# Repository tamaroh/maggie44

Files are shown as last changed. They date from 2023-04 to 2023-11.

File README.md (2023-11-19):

# maggie44
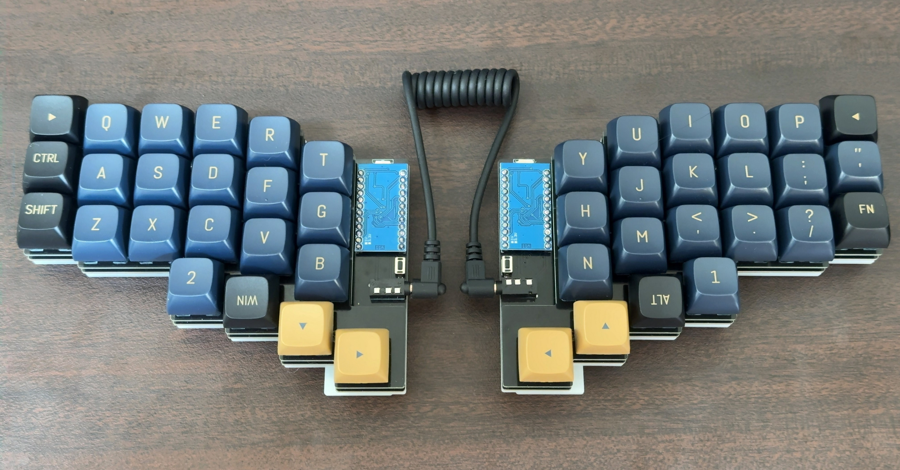
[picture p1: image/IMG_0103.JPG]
maggie44

maggie44はTamarohが初めて作成した試作カスタムキーボードです。
- 左右対象、分割、40%、カラムスタッガード
- T、Yキーがホームポジションに近く押しやすい
- 自然にハの字に手が配置される
- 尺屈角度や頻度を減らし手首にやさしいデザイン

## キーマップ
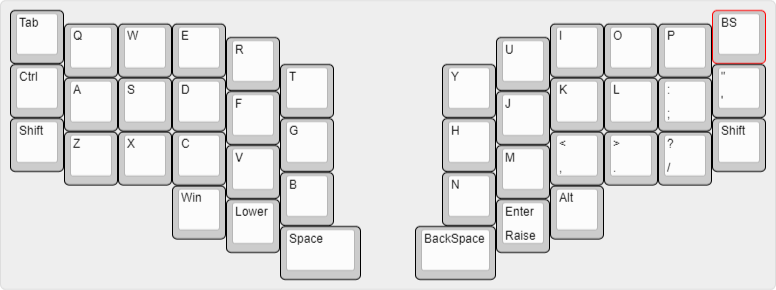
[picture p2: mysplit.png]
keymap

詳細については[ソースコード](https://github.com/tamaroh/qmk_firmware/tree/tamaroh/keyboards/maggie44/keymaps/default)を確認してください

## 必要なもの
|品名|数量|備考|入手先|
|----|----|----|----|
|PCB|2枚|左右別々のデータです<br>ver1.0は一部配線の修正が必要です|このRepositoryのデータから作成してください
|キープレート|2枚|裏返して左右どちらでも使えます|このRepositoryのデータから作成してください
|ボトムプレート大・小|各2枚|アクリル 2mm推奨|このRepositoryのデータから作成してください
|M2ネジ 4mm|20本|ボトムプレートの厚さによって長さは異なります|[遊舎工房](https://shop.yushakobo.jp/products/8006)など
|M2スペーサー 7mm|10個||[遊舎工房](https://shop.yushakobo.jp/products/a0800c2)など
|Pro Micro|2個|すべての互換品については動作を保障しません|[遊舎工房](https://shop.yushakobo.jp/products/pro-micro)など
|ピンヘッダー<br>またはコンスルー|12Pin x 4個||[遊舎工房](https://shop.yushakobo.jp/products/31)など
|タクトスイッチ<br>TS-1136-4.3|2個||[TALP KEYBOARD](https://talpkeyboard.net/items/5fa258a5f0b10814d183347f)など
|ダイオード<br>1N4148|44個|SMD/スルーホール両対応|[TALP KEYBOARD](https://talpkeyboard.net/items/6294480b0ebded1af895c437)など
|スイッチ用PCBソケット|44個|Cherry MX互換のみ対応|[TALP KEYBOARD](https://talpkeyboard.net/items/5e02c5405b120c792616bcf9)など
|TRRSジャック|2個|3.5mm 4極|[TALP KEYBOARD](https://talpkeyboard.net/items/5fa25a06da019c17f0664dc7)など
|TRRSケーブル|1本|TRSでも代用可|[TALP KEYBOARD](https://talpkeyboard.net/items/5e0c0d786c7d63073c5e8845)など
|USBケーブル|1本|Pro MicroとPCを接続できるもの|Amazonなど
|キースイッチ|44個|Cherry MX互換のみ対応|[遊舎工房](https://shop.yushakobo.jp/collections/all-switches)など
|キーキャップ|セット|すべて1Uです|[遊舎工房](https://shop.yushakobo.jp/collections/keycaps)など
|滑り止めゴム足|8個||ダイソーなど

## 必要な工具
- はんだごて
- コテ台、コテ先クリーナー
- はんだ
- 精密ドライバー
- ピンセット

## 制作手順
1. Pro Microにファームウェアを書き込みます。
  QMK Toolboxなどを使用してください。
1. ダイオードを半田付けします。
  SMDの場合縦線が入っている方の端子、スルーホールの場合黒い線がある方の端子を、基板上の縦線がある側に接続してください。
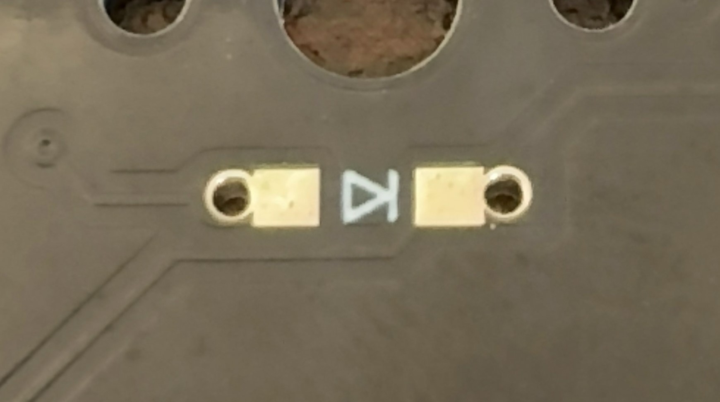
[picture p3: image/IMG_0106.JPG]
  
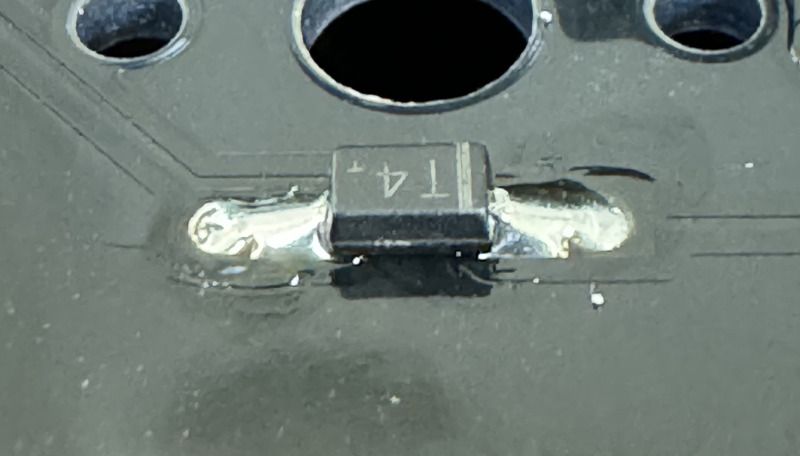
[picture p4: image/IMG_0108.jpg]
  
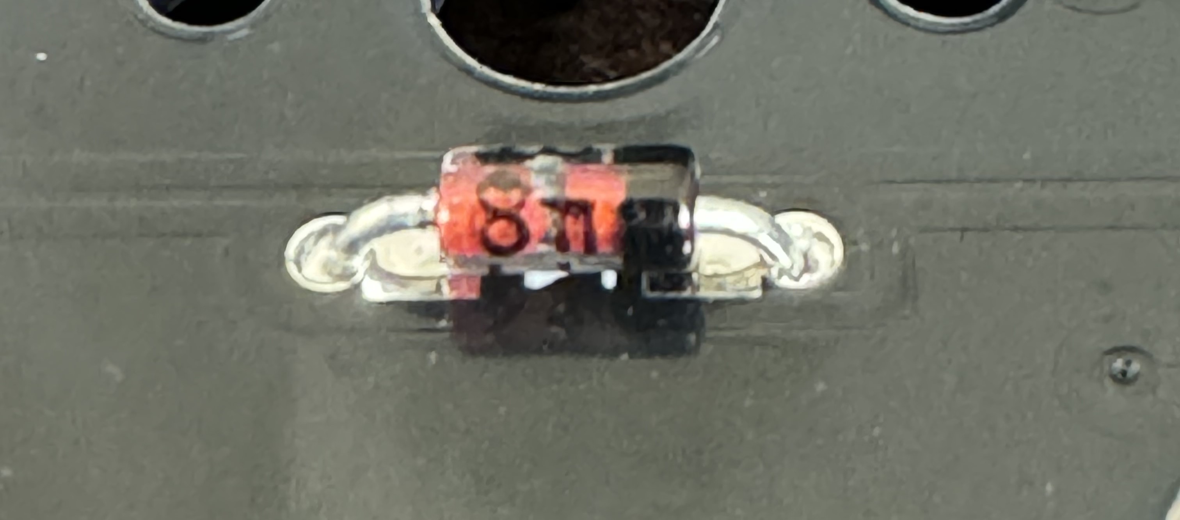
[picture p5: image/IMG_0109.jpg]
  
1. Pro Microを用意します。
  コンスルーを使用する場合は基板に仮置きして、適切にPro Microに半田付けしてください。
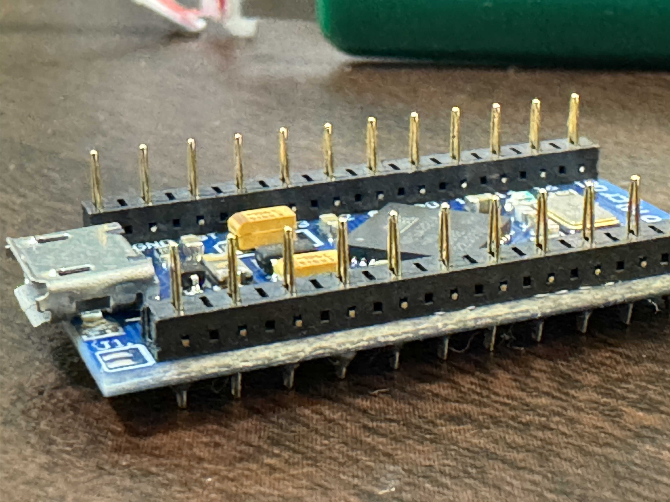
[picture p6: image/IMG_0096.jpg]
  
  ピンヘッダを使用する場合は修正が困難なため、向きや表裏を間違えないようにします。
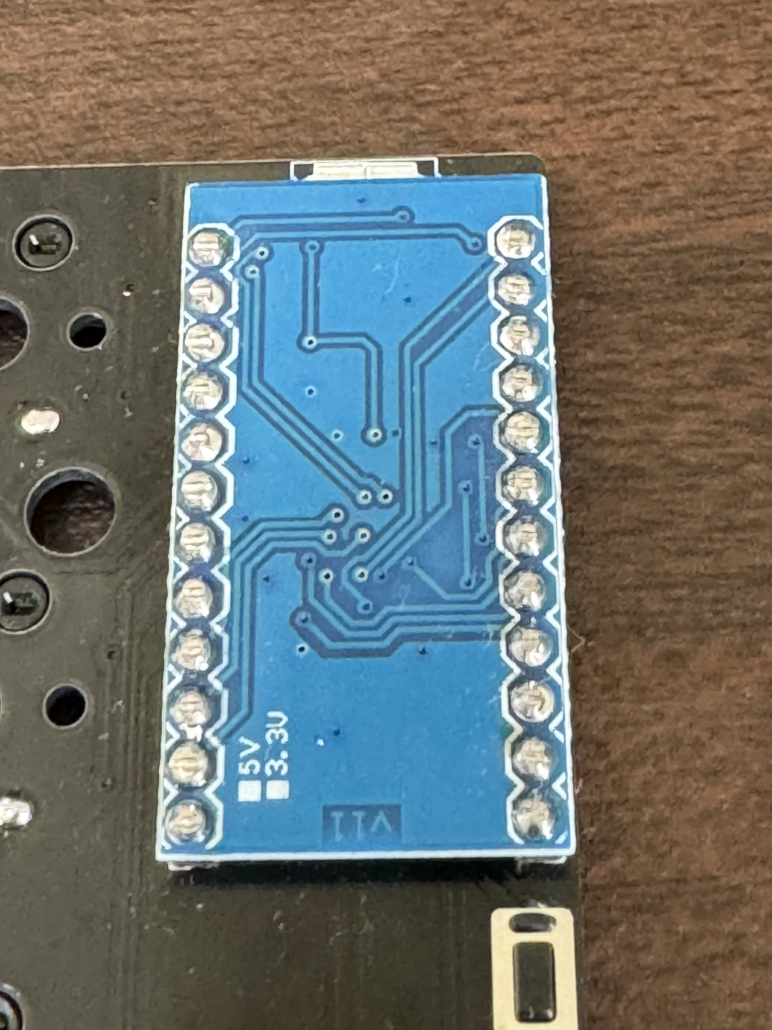
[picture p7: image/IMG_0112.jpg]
  
  ※USB-Cタイプなどコネクタ部が厚い場合は、ピンヘッダの高さが合わなかったり、コンスルーが抜けやすくなる可能性があります。
1. ソケットを半田付けします。シルク印刷に合わせて、スイッチの穴を塞がないようにします。
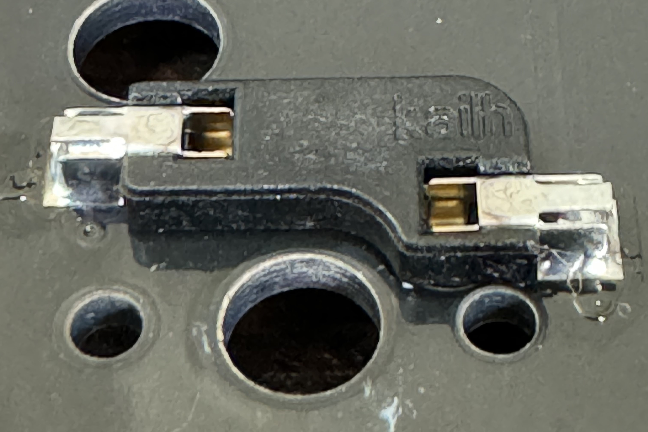
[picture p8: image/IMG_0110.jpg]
  
1. （Ver.1.0の基板のみ）右手用PCBのつながっていない箇所を、銅線などで半田付けしてつなぎます。
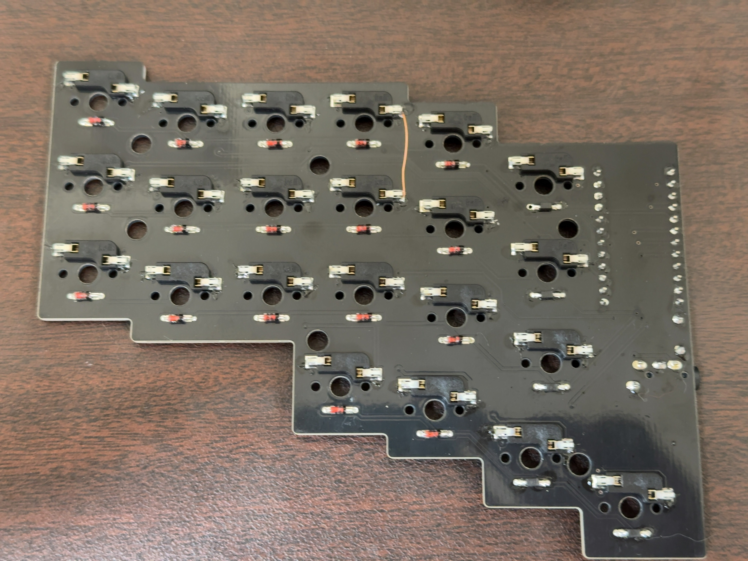
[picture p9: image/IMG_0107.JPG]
  
1. TRRSジャック、リセットスイッチを半田付けします。
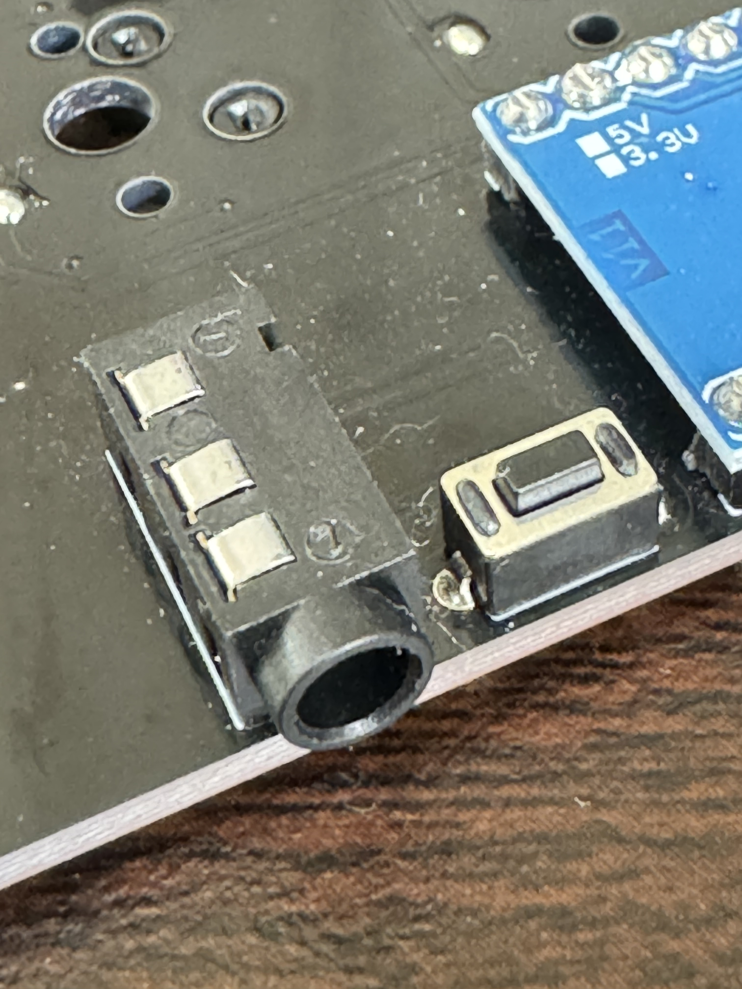
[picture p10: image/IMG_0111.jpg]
  
1. キースイッチを4個程度、先にキープレートに差し込みます。
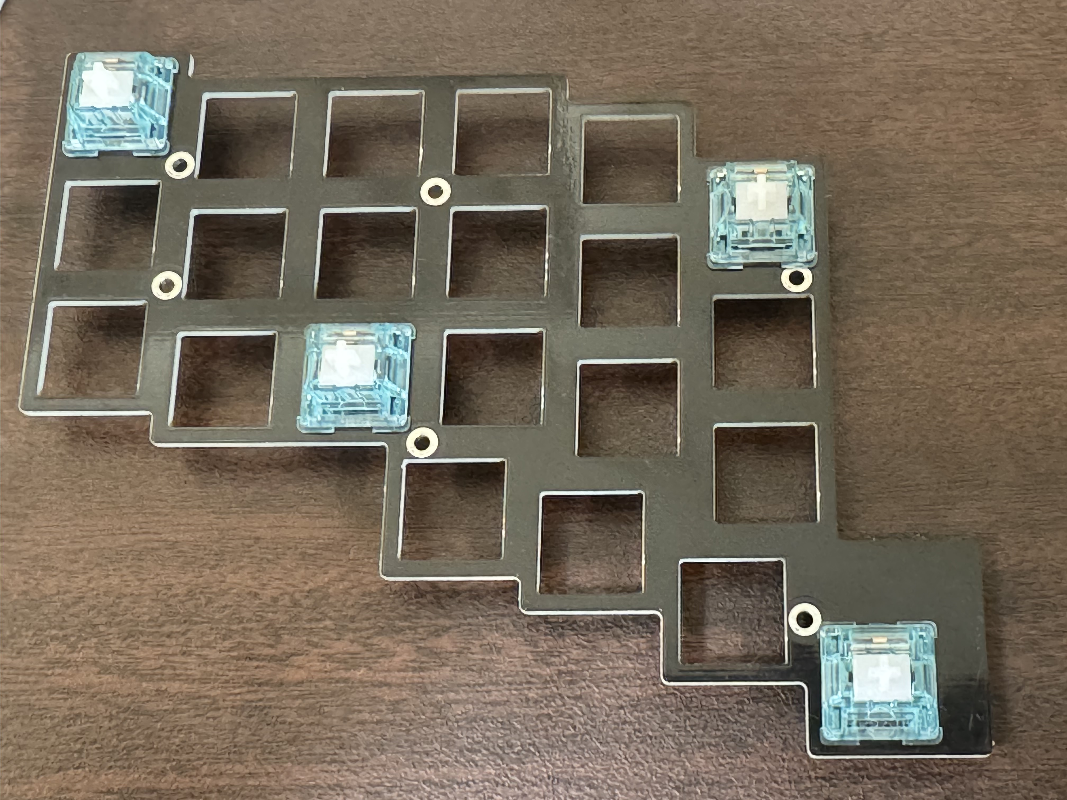
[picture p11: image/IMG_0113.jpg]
  
1.  基板と接続します。スイッチのピンが曲がらないように上からまっすぐ抑えます。
2.  残りのスイッチを差し込みます。ソケットとスイッチを指で挟み込むようにして、ソケットに確実に差し込みます。
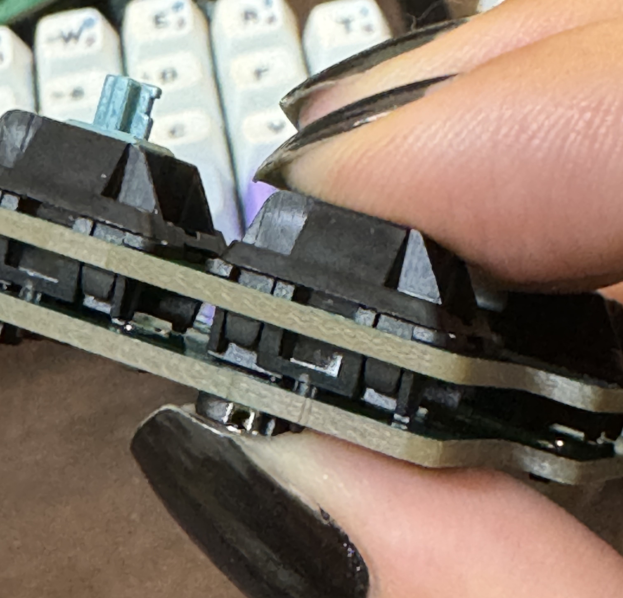
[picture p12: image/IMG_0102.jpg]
  
1. キーキャップを取り付けます。
1. ボトムプレートは、プレート大に足となるスペーサーを先に取り付けてから、本体とネジ止めし、最後にプレート小をネジ止めします。
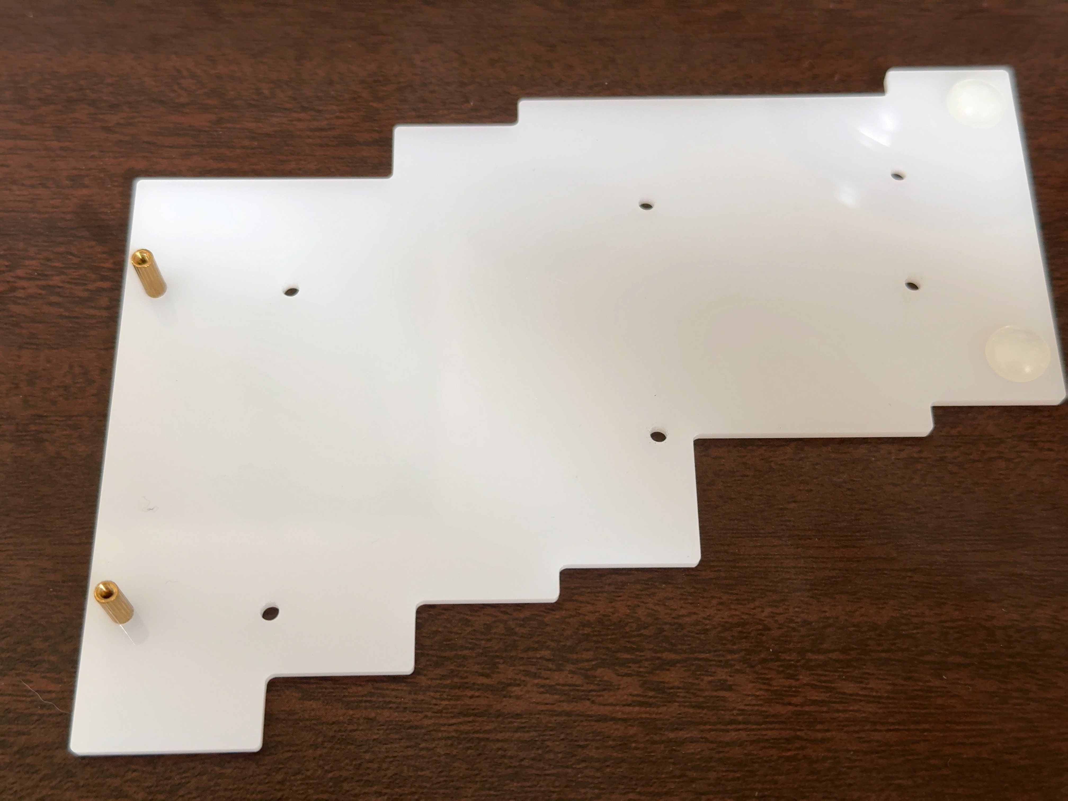
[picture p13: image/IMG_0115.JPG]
  
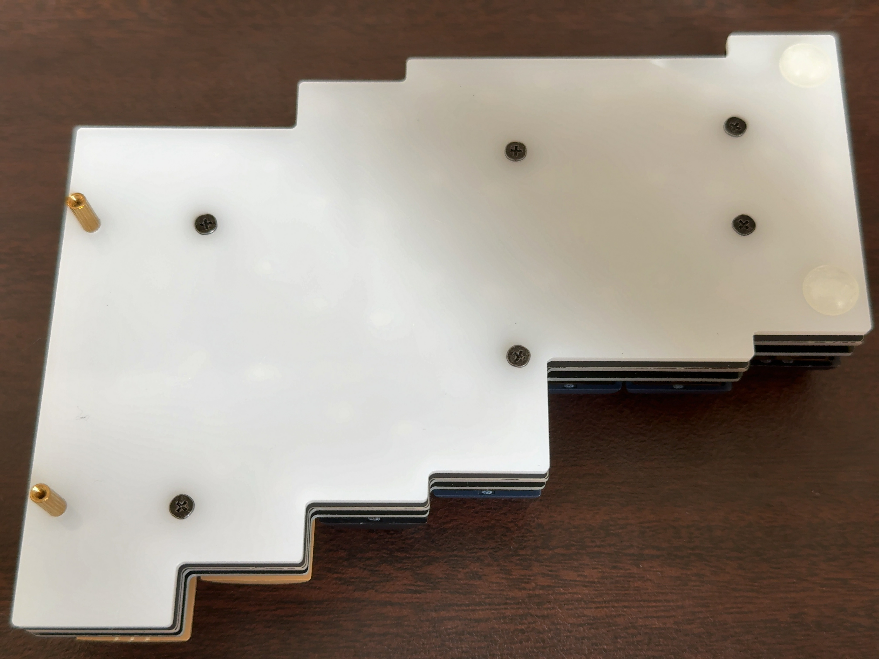
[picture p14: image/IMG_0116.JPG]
  
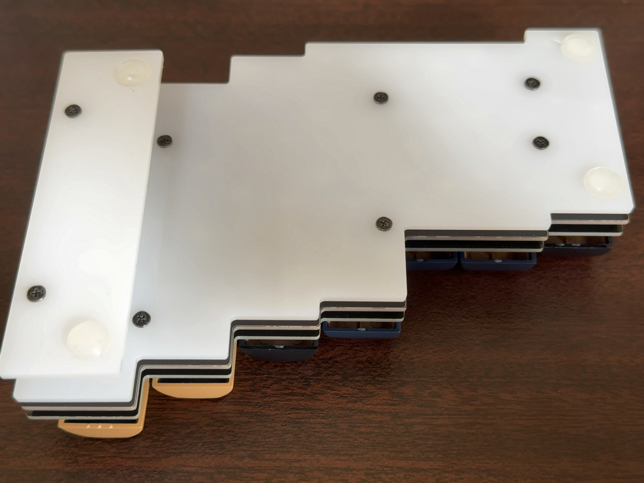
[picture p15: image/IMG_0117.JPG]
  
1. プレート大・小にゴム足を取り付けます。
1. できあがり
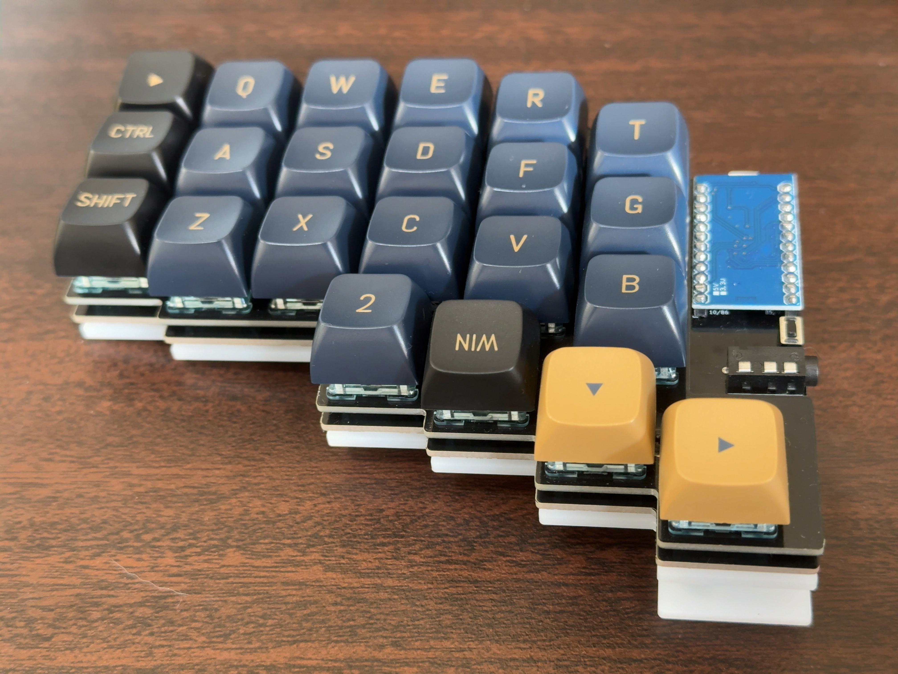
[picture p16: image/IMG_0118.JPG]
  

## ファームウェアについて
ファームウェアは以下にあります。
https://github.com/tamaroh/maggie44/tree/main/firmware
ファイル名|備考
|----|----|
|maggie44_default.hex|VIA有効|
|maggie44_via.json|VIAでキーマップ設定時に使用してください|

ソースコード
https://github.com/tamaroh/qmk_firmware/tree/tamaroh/keyboards/tamaroh/maggie44

## 注意事項
- 非販売品につき、制作に関するサポートはいたしません。
- 試作のため、当レポジトリ内のデータが不完全である可能性があります。

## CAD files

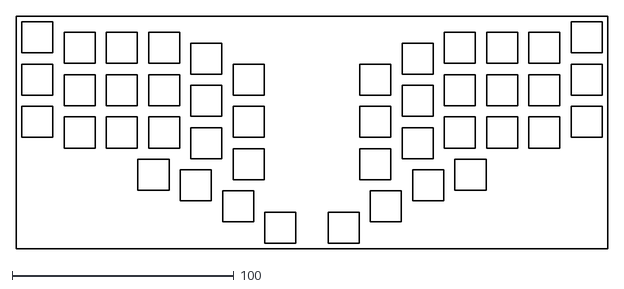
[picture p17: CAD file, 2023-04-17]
mysplit.dxf
266.7 x 104.8

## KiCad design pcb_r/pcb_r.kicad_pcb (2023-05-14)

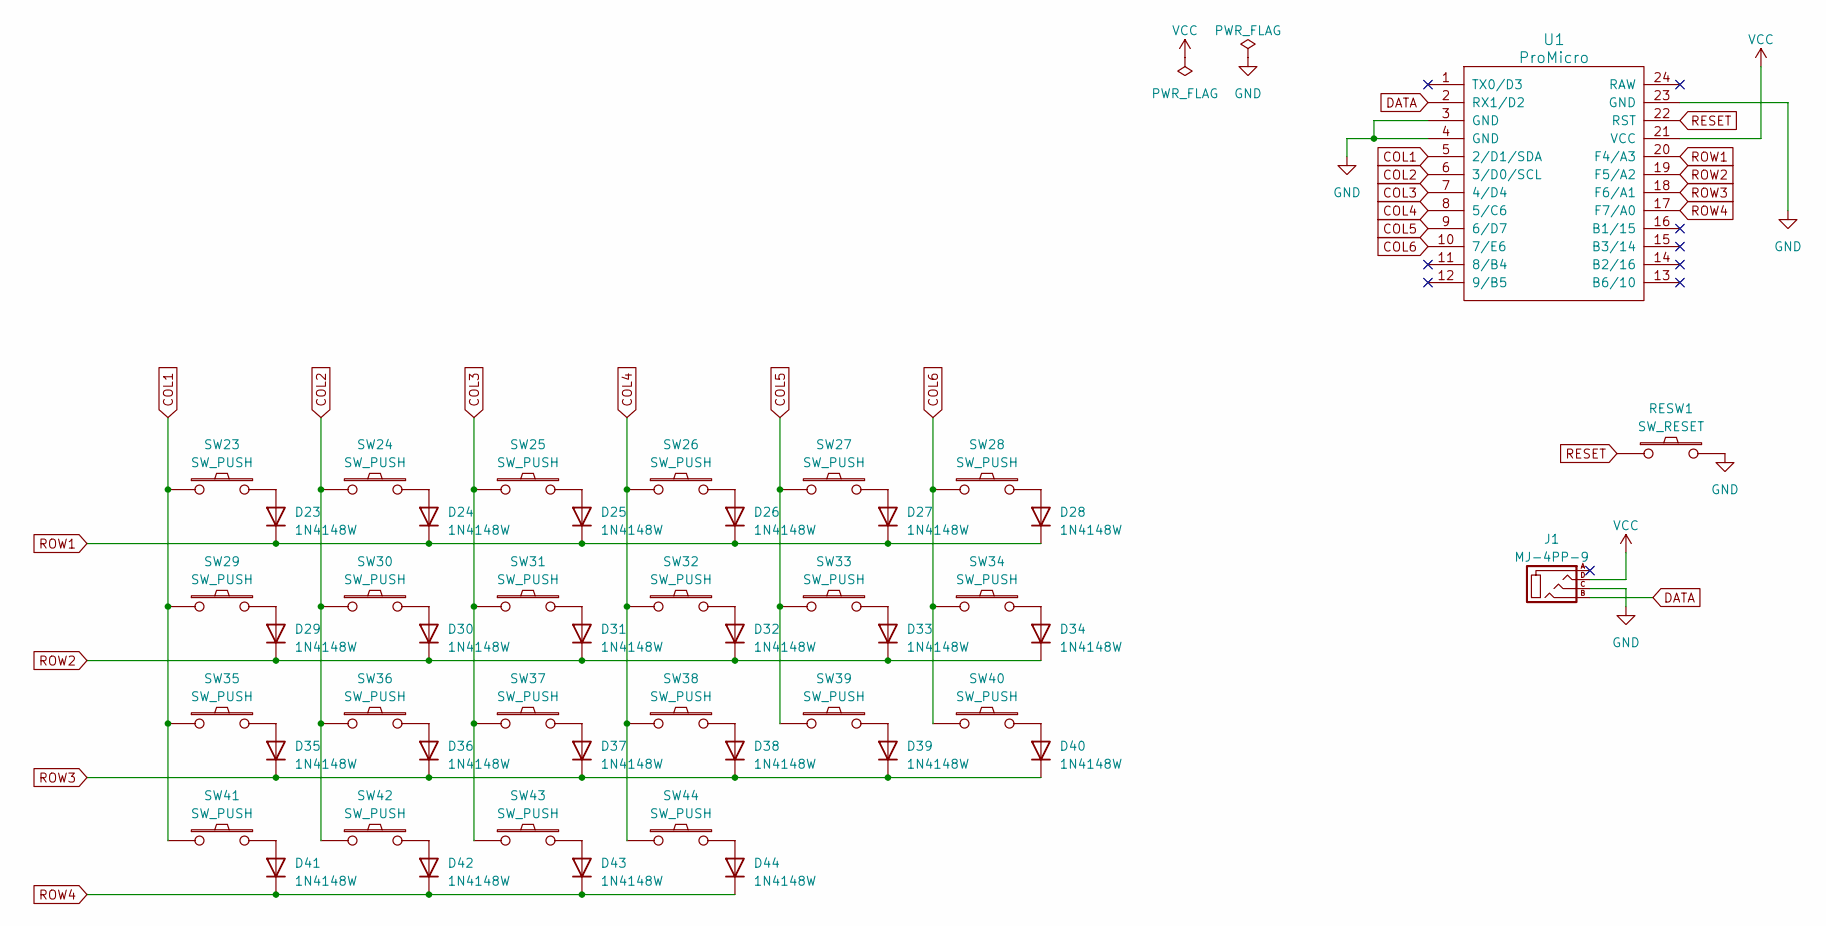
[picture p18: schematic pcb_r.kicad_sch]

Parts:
D23, D24, D25, D26, D27, D28, D29, D30, D31, D32, D33, D34, D35, D36, D37, D38, D39, D40, D41, D42, D43, D44: 1N4148W; D3_TH_SMD_v2
J1: MJ-4PP-9; MJ-4PP-9_1side
RESW1: SW_RESET; ResetSW_1side
SW23, SW24, SW25, SW26, SW27, SW28, SW29, SW30, SW31, SW32, SW33, SW34, SW35, SW36, SW37, SW38, SW39, SW40, SW41, SW42, SW43, SW44: SW_PUSH; CherryMX_Hotswap
U1: ProMicro; ProMicro_v3

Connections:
COL1: SW23.1, SW29.1, SW35.1, SW41.1, U1.5 (2/D1/SDA)
COL2: SW24.1, SW30.1, SW36.1, SW42.1, U1.6 (3/D0/SCL)
COL3: SW25.1, SW31.1, SW37.1, SW43.1, U1.7 (4/D4)
COL4: SW26.1, SW32.1, SW38.1, SW44.1, U1.8 (5/C6)
COL5: SW27.1, SW33.1, SW39.1, U1.9 (6/D7)
COL6: SW28.1, SW34.1, SW40.1, U1.10 (7/E6)
DATA: J1.B, U1.2 (RX1/D2)
GND: J1.C, RESW1.2, U1.3 (GND), U1.4 (GND), U1.23 (GND)
unnamed: D23.2 (A), SW23.2
unnamed: D24.2 (A), SW24.2
unnamed: D25.2 (A), SW25.2
unnamed: D26.2 (A), SW26.2
unnamed: D27.2 (A), SW27.2
unnamed: D28.2 (A), SW28.2
unnamed: D29.2 (A), SW29.2
unnamed: D30.2 (A), SW30.2
unnamed: D31.2 (A), SW31.2
unnamed: D32.2 (A), SW32.2
unnamed: D33.2 (A), SW33.2
unnamed: D34.2 (A), SW34.2
unnamed: D35.2 (A), SW35.2
unnamed: D36.2 (A), SW36.2
unnamed: D37.2 (A), SW37.2
unnamed: D38.2 (A), SW38.2
unnamed: D39.2 (A), SW39.2
unnamed: D40.2 (A), SW40.2
unnamed: D41.2 (A), SW41.2
unnamed: D42.2 (A), SW42.2
unnamed: D43.2 (A), SW43.2
unnamed: D44.2 (A), SW44.2
RESET: RESW1.1, U1.22 (RST)
ROW1: D23.1 (K), D24.1 (K), D25.1 (K), D26.1 (K), D27.1 (K), D28.1 (K), U1.20 (F4/A3)
ROW2: D29.1 (K), D30.1 (K), D31.1 (K), D32.1 (K), D33.1 (K), D34.1 (K), U1.19 (F5/A2)
ROW3: D35.1 (K), D36.1 (K), D37.1 (K), D38.1 (K), D39.1 (K), D40.1 (K), U1.18 (F6/A1)
ROW4: D41.1 (K), D42.1 (K), D43.1 (K), D44.1 (K), U1.17 (F7/A0)
VCC: J1.D, U1.21 (VCC)

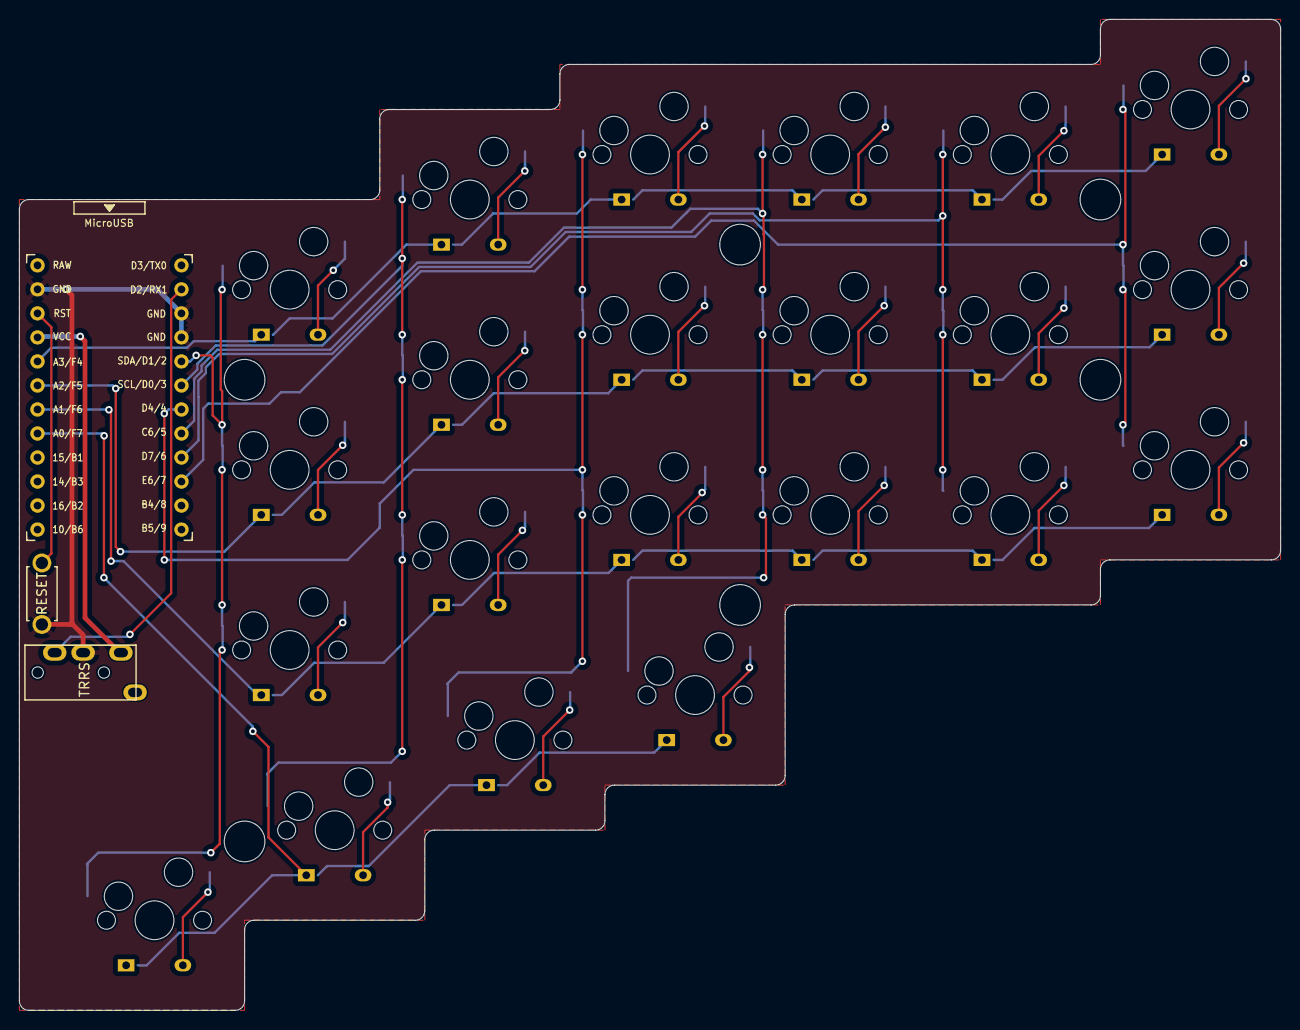
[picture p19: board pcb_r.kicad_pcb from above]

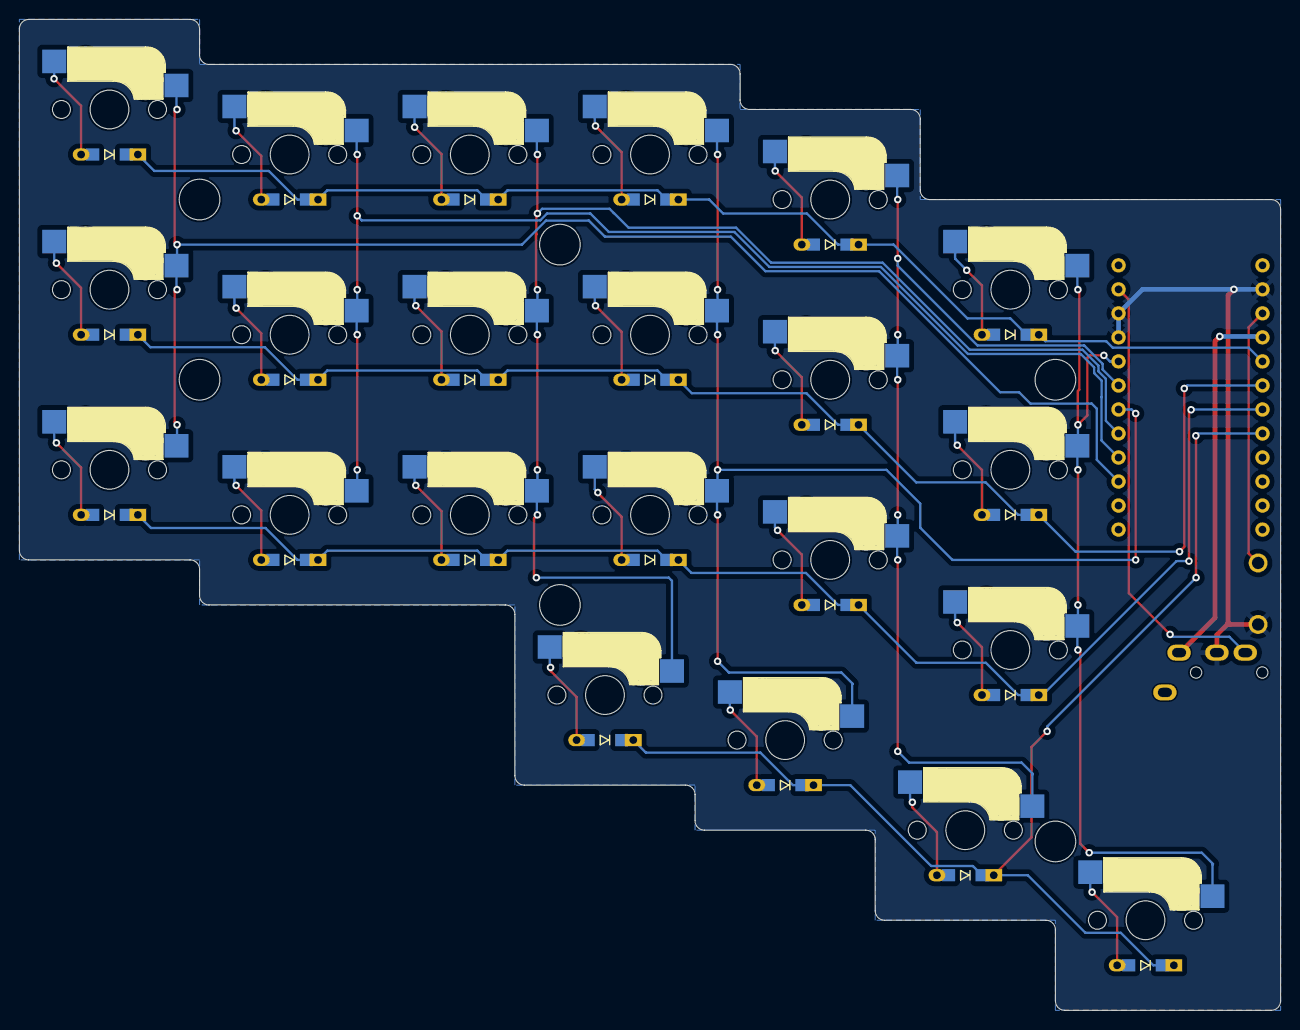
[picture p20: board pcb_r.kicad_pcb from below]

Board: 2 copper layers, 133.4 x 104.8 mm, 53 parts (22 on the bottom side), 36 nets.

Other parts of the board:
Ref**: Val**; spacer_m2
Ref**#2, Ref**#3, Ref**#4, Ref**#5, Ref**#6: Val**; spacer_m2

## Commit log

2023-04-11 added submodule from foostan/kbd
    [mysplit44_pcb_l.kicad_pcb, mysplit44_pcb_l.kicad_sch]
2023-04-11 added footprints & libraries
2023-04-17 created circuit edit
    [mysplit44_pcb_l.kicad_sch]
2023-04-17 layout done
    [mysplit.dxf, mysplit44_pcb_l.kicad_pcb, mysplit44_pcb_l.kicad_sch]
2023-04-23 finished right layout
    [pcb_r.kicad_pcb, pcb_r.kicad_sch]
2023-04-23 fixed folder structure
    [pcb_r.kicad_pcb, pcb_r.kicad_sch]
2023-04-23 added topplate-l, fixed pcb-l hole
    [mysplit44_pcb_l.kicad_pcb, topplate_l.kicad_pcb, topplate_l.kicad_sch]
2023-04-23 added bottomplate
    [bottomplate_l.kicad_pcb, bottomplate_l.kicad_sch]
2023-04-23 added footplate
    [foorplate_l.kicad_pcb, foorplate_l.kicad_sch]
2023-04-23 added gnd mask
    [bottomplate_l.kicad_pcb, foorplate_l.kicad_pcb, mysplit44_pcb_l.kicad_pcb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]
2023-04-23 added plate files
    [mysplit44_pcb_l-B_Cu.gbl, mysplit44_pcb_l-B_Mask.gbs, mysplit44_pcb_l-B_Paste.gbp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]
2023-05-06 fixed for order
    [topplate_l-B_Cu.gbl, topplate_l-B_Mask.gbs, topplate_l-B_Paste.gbp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]
2023-05-06 fixed hole size
    [bottomplate_l.kicad_pcb, foorplate_l.kicad_pcb]
2023-05-14 fixed #4
    [pcb_r.kicad_pcb]
2023-05-14 fixed #6
    [topplate_l.kicad_pcb]
